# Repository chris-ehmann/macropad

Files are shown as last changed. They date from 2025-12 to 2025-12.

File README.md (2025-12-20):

# Macropad

I've been interested in mechanical keyboards for a while now, and recently I wanted to get a bit of experience writing firmware, so I decided to combine these two interests and create a mechanical keyboard from scratch (well, as close to "from scratch" as reasonably possible).

## Designing the PCB

The hardware design for a keyboard is fairly straightforward. A lot of credit here goes to ai03's guide located [here](https://wiki.ai03.com/books/pcb-design/), which gives pretty good direction on what a properly designed circuit should look like. Of course, I wanted to actually learn what was going on in the circuit that I was replicating, so I made sure to supplement this with reading through datasheets and general studying. I think I can confidently state what a pull-up resistor now does, at the very least.

Even though this is a 6-key keypad (which means each switch could be directly connected to it's own pin), I thought a keyboard matrix circuit would be more fun to implement. The premise here is pretty straightforward: since there aren't enough pins on microcontrollers to directly connect each switch to a key, you have to get a bit creative and arrange switches in a grid-like formation. Then, each switch will be connected to a specific grid pin and to a specific row pin. Now, say you have current flowing through a specific column, if any of the keys connected in that column are pressed, you'll be able to figure that out by simplying checking the corresponding row pins for any input. There's a few things to be considerate of however -- primarily [ghosting](https://www.dribin.org/dave/keyboard/one_html/).

## Soldering

I've never soldered before, so I thought this would be a great opportunity to learn. There's a few components that I thought would be near impossible for me to solder as a beginner (e.g., the USB Micro-B connector, the ATMEGA32U4 microcontroller, and whatever other SMD  components), so I opted for these to be assembled by the PCB manufacturer (in my case, JLCPCB). The switches however, being through-hole, felt a little bit more in my ballpark. 

For soldering equipment, I didn't have anything on hand so I ended up grabbing myself a [PINECIL](https://pine64.com/product/pinecil-smart-mini-portable-soldering-iron/). It seems to be pretty highly recommended and I can understand why; it felt very easy to use. Maybe in the future if I do more soldering I might pick up something more heavy-duty, like a hot air rework station.

## Firmware

The firmware I've written for this uses [LUFA](https://github.com/abcminiuser/lufa) to communicate via USB. I'm new to this framework, so I've built upon the Keyboard demo that's generously provided with LUFA. The relevant keypad code (e.g. what actually sets up our pins, scans through the matrix, handles debouncing, etc.) can be found in `macropad_firmware/macropad_firmware/Keyboard.c`. I do eventually want to move this out of a demo and into something built up from scratch (albeit while still using LUFA), but for now this has worked very well for a first revision.

The firmware is pretty basic: for scanning the matrix, we set each row to output LOW, and then we scan each column (configured to be input with pull-up resistor active) to detect which keys are pressed. We then store the number of scan-cycles a key has been pressed for, and once it hits some debouncing threshold (I've chosen 10, which corresponds to about a 5ms debounce period. The datasheet for the Cherry-MX Brown switches that I'm using state that the bounce time is <2 msec, so it's slightly overkill) we can then send it over in the next USB report.

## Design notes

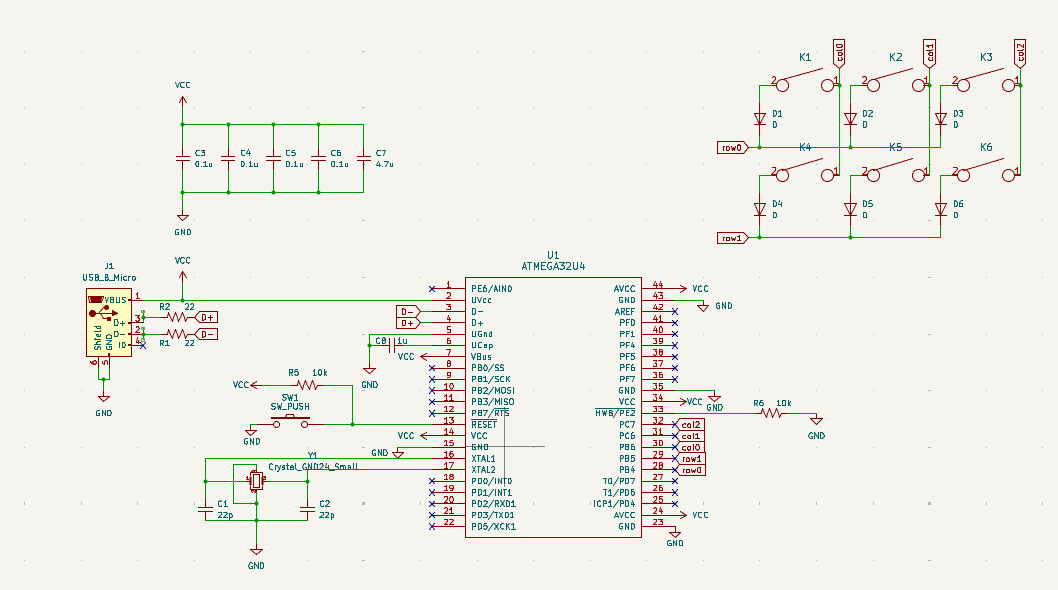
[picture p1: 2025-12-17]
macropad/macropad_schematic.png

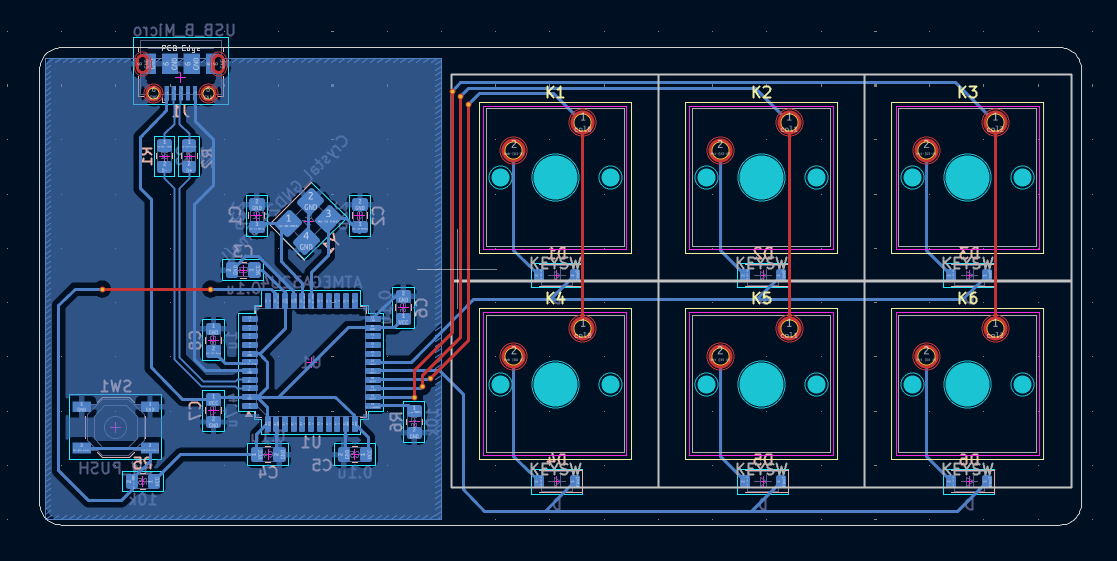
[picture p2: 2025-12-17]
macropad/macropad_pcb.png

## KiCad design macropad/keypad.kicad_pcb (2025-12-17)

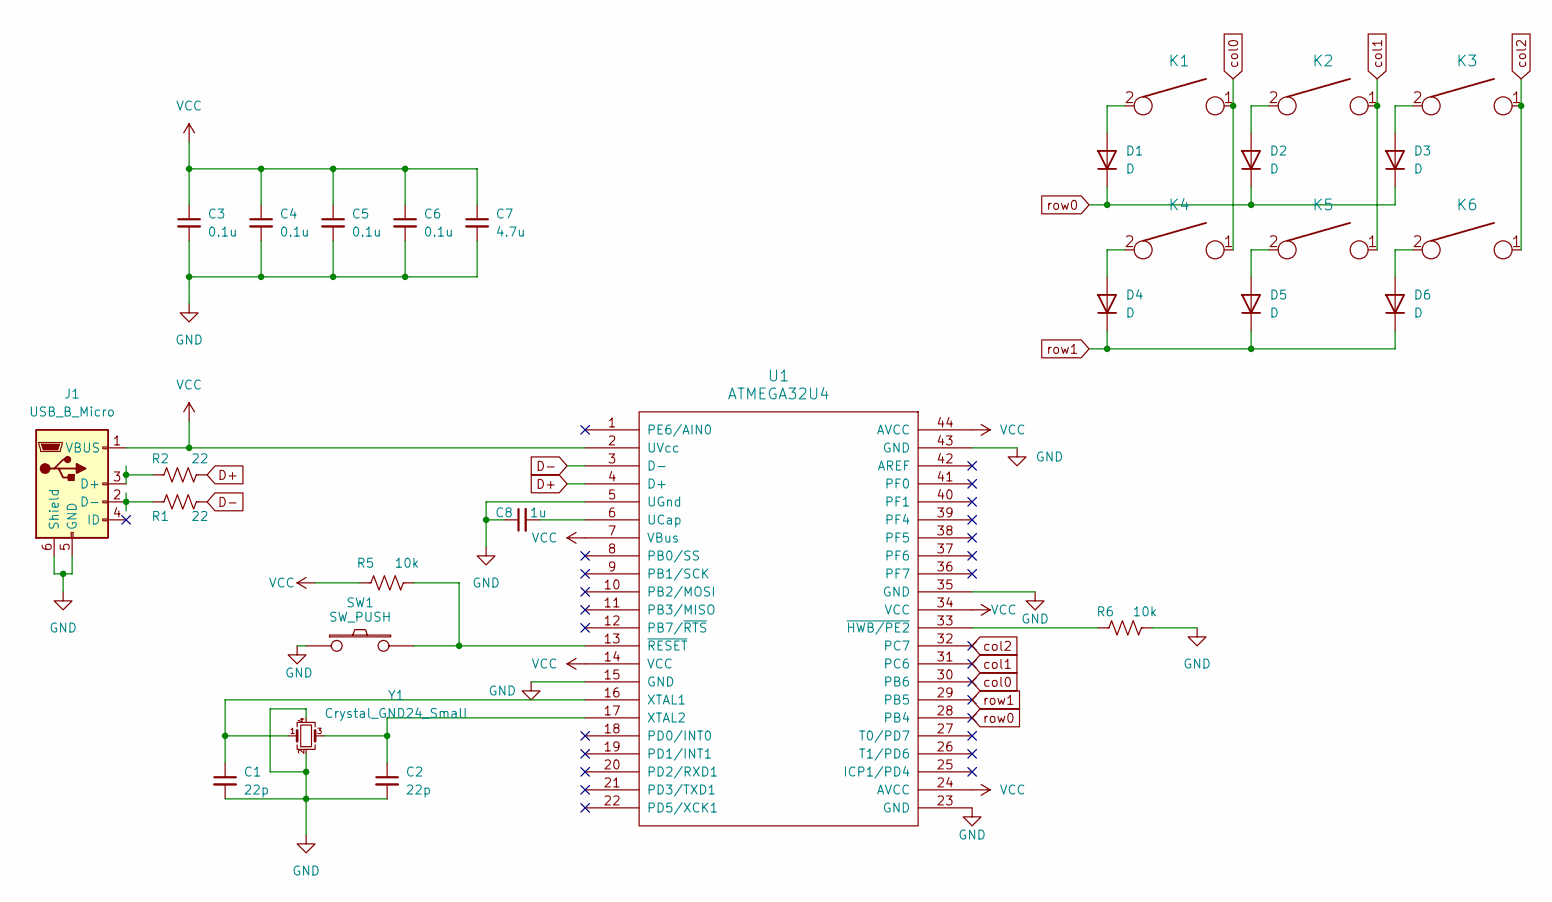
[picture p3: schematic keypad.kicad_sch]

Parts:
C1, C2: 22p; C_0805_2012Metric_Pad1.18x1.45mm_HandSolder
C3, C4, C5, C6: 0.1u; C_0805_2012Metric_Pad1.18x1.45mm_HandSolder
C7: 4.7u; C_0805_2012Metric_Pad1.18x1.45mm_HandSolder
C8: 1u; C_0805_2012Metric_Pad1.18x1.45mm_HandSolder
D1, D2, D3, D4, D5, D6: D; D_SOD-123
J1: USB_B_Micro; USB_Micro-B_Molex-105017-0001
K1, K2, K3, K4, K5, K6: KEYSW; SW_Cherry_MX_1.00u_PCB
R1, R2: 22; R_0805_2012Metric_Pad1.20x1.40mm_HandSolder
R5, R6: 10k; R_0805_2012Metric_Pad1.20x1.40mm_HandSolder
SW1: SW_PUSH; SW_SPST_TL3342
U1: ATMEGA32U4; TQFP-44_10x10mm_P0.8mm
Y1: Crystal_GND24_Small; Crystal_SMD_3225-4Pin_3.2x2.5mm_HandSoldering

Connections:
D+: R2.2, U1.4 (D+)
D-: R1.2, U1.3 (D-)
GND: C1.2, C2.2, C3.2, C4.2, C5.2, C6.2, C7.2, C8.1, J1.5 (GND), J1.6 (Shield), R6.2, SW1.1, U1.5 (UGnd), U1.15 (GND), U1.23 (GND), U1.35 (GND), U1.43 (GND), Y1.2, Y1.4
unnamed: D1.2 (A), K1.2
unnamed: D2.2 (A), K2.2
unnamed: D3.2 (A), K3.2
unnamed: D4.2 (A), K4.2
unnamed: D5.2 (A), K5.2
unnamed: D6.2 (A), K6.2
unnamed: J1.3 (D+), R2.1
unnamed: J1.2 (D-), R1.1
unnamed: C8.2, U1.6 (UCap)
unnamed: C1.1, U1.16 (XTAL1), Y1.1
unnamed: C2.1, U1.17 (XTAL2), Y1.3
unnamed: R6.1, U1.33 (~HWB/PE2)
unnamed: R5.2, SW1.2, U1.13 (~RESET)
VCC: C3.1, C4.1, C5.1, C6.1, C7.1, J1.1 (VBUS), R5.1, U1.2 (UVcc), U1.7 (VBus), U1.14 (VCC), U1.24 (AVCC), U1.34 (VCC), U1.44 (AVCC)
col0: K1.1, K4.1, U1.30 (PB6)
col1: K2.1, K5.1, U1.31 (PC6)
col2: K3.1, K6.1, U1.32 (PC7)
row0: D1.1 (K), D2.1 (K), D3.1 (K), U1.28 (PB4)
row1: D4.1 (K), D5.1 (K), D6.1 (K), U1.29 (PB5)

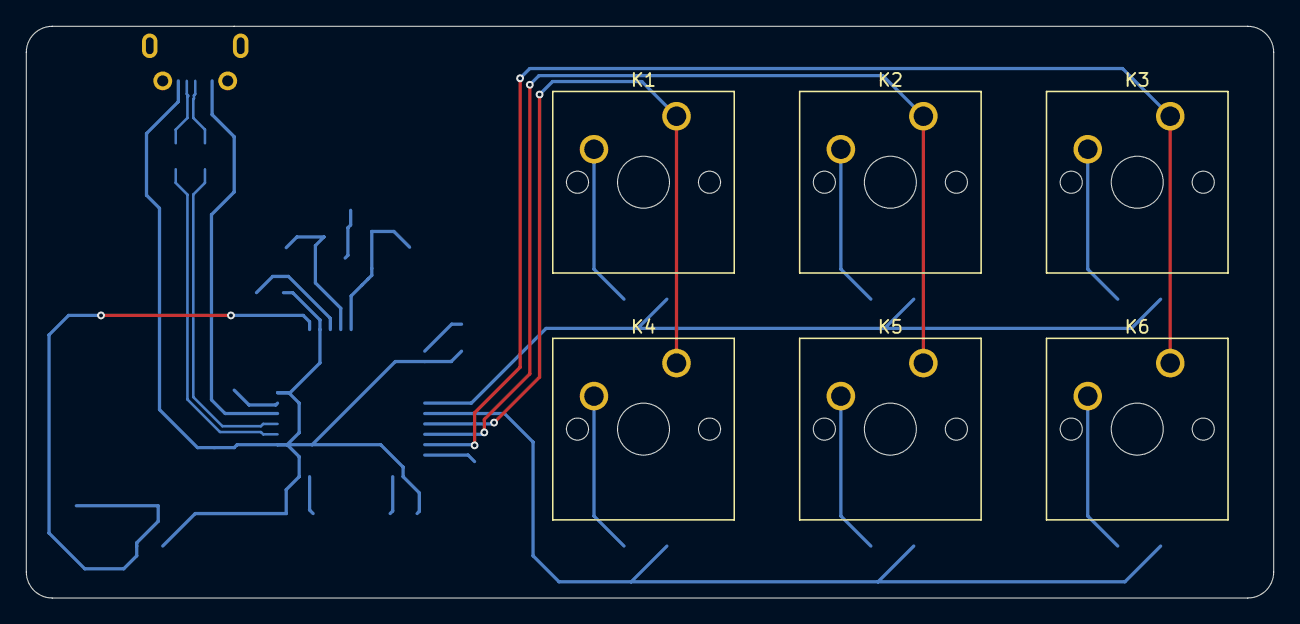
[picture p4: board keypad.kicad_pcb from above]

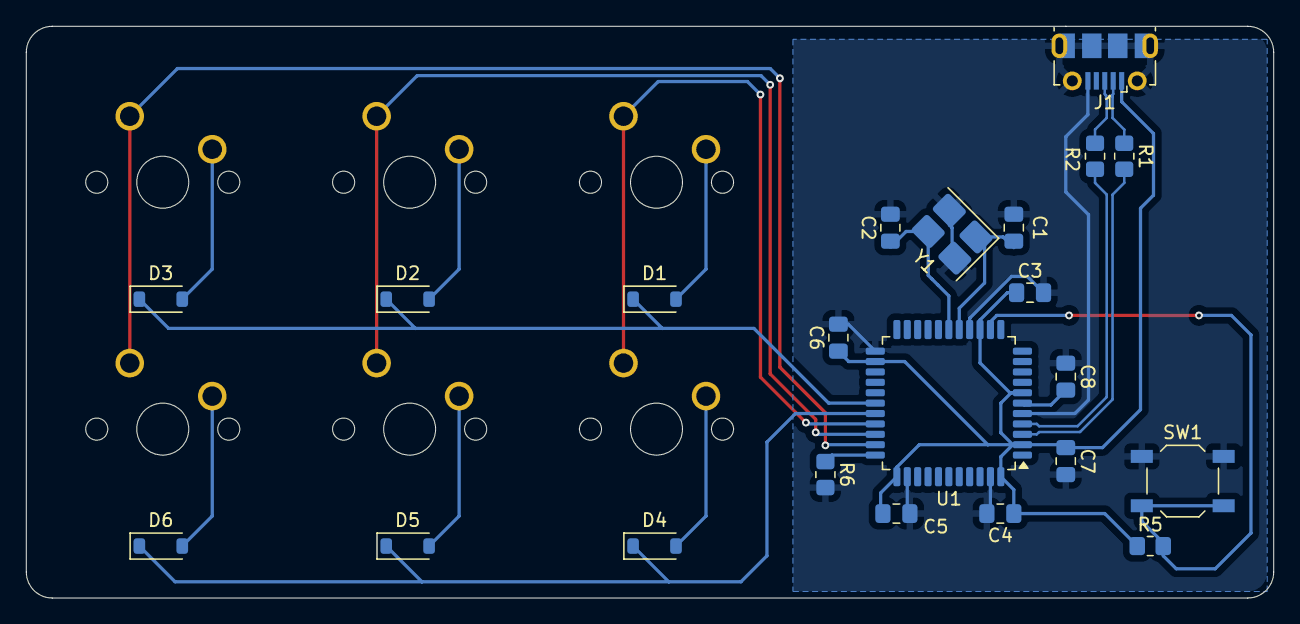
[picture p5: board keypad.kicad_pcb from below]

Board: 2 copper layers, 96.0 x 44.0 mm, 28 parts (22 on the bottom side), 22 nets.

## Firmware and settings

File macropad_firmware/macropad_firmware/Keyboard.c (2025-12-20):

/*
             LUFA Library
     Copyright (C) Dean Camera, 2017.

  dean [at] fourwalledcubicle [dot] com
           www.lufa-lib.org
*/

/*
  Copyright 2017  Dean Camera (dean [at] fourwalledcubicle [dot] com)
  Copyright 2010  Denver Gingerich (denver [at] ossguy [dot] com)

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
  The author disclaims all warranties with regard to this
  software, including all implied warranties of merchantability
  and fitness.  In no event shall the author be liable for any
  special, indirect or consequential damages or any damages
  whatsoever resulting from loss of use, data or profits, whether
  in an action of contract, negligence or other tortious action,
  arising out of or in connection with the use or performance of
  this software.
*/

#include "Keyboard.h"
#include <stdint.h>
#include <util/delay.h>

/** Indicates what report mode the host has requested, true for normal HID reporting mode, \c false for special boot
 *  protocol reporting mode.
 */
static bool UsingReportProtocol = true;

/** Current Idle period. This is set by the host via a Set Idle HID class request to silence the device's reports
 *  for either the entire idle duration, or until the report status changes (e.g. the user presses a key).
 */
static uint16_t IdleCount = 500;

/** Current Idle period remaining. When the IdleCount value is set, this tracks the remaining number of idle
 *  milliseconds. This is separate to the IdleCount timer and is incremented and compared as the host may request
 *  the current idle period via a Get Idle HID class request, thus its value must be preserved.
 */
static uint16_t IdleMSRemaining = 0;

#define DEBOUNCE_THRESHOLD  10
#define LAYER_SWITCH        0x00
#define NUM_COLS            3
#define NUM_ROWS            2
#define PIN_DEF(port, pin)  { &PIN##port, &DDR##port, &PORT##port, pin }
#define layer_count(a)      (sizeof(a) / sizeof(a[0]))
	
typedef struct
{
	volatile uint8_t *pin;
	volatile uint8_t *ddr;
	volatile uint8_t *port;
	uint8_t pin_n;
} gpio_pin_t;

const gpio_pin_t COLS[NUM_COLS]							   = { PIN_DEF(B, 6), PIN_DEF(C, 6), PIN_DEF(C, 7) };
const gpio_pin_t ROWS[NUM_ROWS]						       = { PIN_DEF(B, 4), PIN_DEF(B, 5) };
uint8_t debounce_keys[NUM_ROWS][NUM_COLS]				   = {{0, 0, 0}, {0, 0, 0}}; // Matrix to store the amount of cycles a key has been held down for. Caps out at DEBOUNCE_THRESHOLD to avoid integer overflow
	
// Matrix that stores each layer of our keypad. Key in row 0 column 0 is marked as LAYER_SWITCH as it corresponds
// to a special key on the keyboard that swaps between layers (and doesn't actually send any data)
const unsigned char keycodes[][NUM_ROWS][NUM_COLS] PROGMEM = 
  															 { { {LAYER_SWITCH, HID_KEYBOARD_SC_4_AND_DOLLAR, HID_KEYBOARD_SC_5_AND_PERCENTAGE},
															     {HID_KEYBOARD_SC_1_AND_EXCLAMATION, HID_KEYBOARD_SC_2_AND_AT, HID_KEYBOARD_SC_3_AND_HASHMARK}, },
														
															   { {LAYER_SWITCH, HID_KEYBOARD_SC_9_AND_OPENING_PARENTHESIS, HID_KEYBOARD_SC_0_AND_CLOSING_PARENTHESIS},
															     {HID_KEYBOARD_SC_6_AND_CARET, HID_KEYBOARD_SC_7_AND_AMPERSAND, HID_KEYBOARD_SC_8_AND_ASTERISK} } };
												   
/*  Keyboard layout, as a diagram (! designates SWAP layer key)
	NOTE: Only top layer keys are shown
   +-----------------------------+
   |         |         |         |
   |    !    |    4    |    5    |
   |         |         |         |
   +-----------------------------+
   |         |         |         |
   |    1    |    2    |    3    |
   |         |         |         |
   +-----------------------------+
*/

// Set up appropriate GPIO pins for keypad matrix
static void io_config()
{
	// Initially set up our row pins (which will be used as output pins) as input (Hi-Z)
	for(int i = 0; i < NUM_ROWS; i++)
	{
		*ROWS[i].ddr &= ~(1 << ROWS[i].pin_n);
	}
	
	// Set up our column pins to be input and activate the internal pull-up resistor
	for(int i = 0; i < NUM_COLS; i++)
	{
		*COLS[i].ddr &= ~(1 << COLS[i].pin_n);
		*COLS[i].port |= (1 << COLS[i].pin_n);
	}
}

static bool is_key_pressed(uint8_t row, uint8_t col)
{
	return debounce_keys[row][col] == DEBOUNCE_THRESHOLD;
}

// Performs a scan over the entire keyboard matrix and updates key states accordingly
static void scan_matrix()
{
	for(uint8_t row = 0; row < NUM_ROWS; row++)
	{
		// Set current row to output; drive it low
		*ROWS[row].ddr |= (1 << ROWS[row].pin_n);
		*ROWS[row].port &= ~(1 << ROWS[row].pin_n);
			
		// Slight delay to allow row to settle
		_delay_us(20);
			
		// Iterate over each column to detect which keys are pressed in this row
		for(uint8_t col = 0; col < NUM_COLS; col++)
		{
			uint8_t pressed = 0;
			pressed = (*COLS[col].pin & (1 << COLS[col].pin_n)) == 0; // Check if pin corresponding to column is low (meaning the key is pressed) or high (key is not pressed)
			if(pressed)
			{
				if(debounce_keys[row][col] < DEBOUNCE_THRESHOLD)
				{
					debounce_keys[row][col]++;
				}
				continue;
			}

			if(debounce_keys[row][col] > 0)
			{
				debounce_keys[row][col]--;
			}
		}
		
		// Switch row back to being input
		*ROWS[row].ddr &= ~(1 << ROWS[row].pin_n);
	}	
}

int main(void)
{
	SetupHardware();
	io_config();
	GlobalInterruptEnable();

	while(1)
	{
		scan_matrix();
		
		// Send data (either pressed keys, or nothing) through USB connection
		HID_Task();
		USB_USBTask();
		
		// Half a millisecond delay between full scans corresponds to about 5ms to fully debounce a key (given DEBOUNCE_THRESHOLD = 10)
		_delay_us(500);
	}
}

/** Configures the board hardware and chip peripherals for the demo's functionality. */
void SetupHardware(void)
{
	/* Disable watchdog if enabled by bootloader/fuses */
	MCUSR &= ~(1 << WDRF);
	wdt_disable();

	/* Disable clock division */
	clock_prescale_set(clock_div_1);
	USB_Init();
}

/** Event handler for the USB_ConfigurationChanged event. This is fired when the host sets the current configuration
 *  of the USB device after enumeration, and configures the keyboard device endpoints.
 */
void EVENT_USB_Device_ConfigurationChanged(void)
{
	bool ConfigSuccess = true;

	/* Setup HID Report Endpoints */
	ConfigSuccess &= Endpoint_ConfigureEndpoint(KEYBOARD_IN_EPADDR, EP_TYPE_INTERRUPT, KEYBOARD_EPSIZE, 1);
	ConfigSuccess &= Endpoint_ConfigureEndpoint(KEYBOARD_OUT_EPADDR, EP_TYPE_INTERRUPT, KEYBOARD_EPSIZE, 1);

	/* Turn on Start-of-Frame events for tracking HID report period expiry */
	USB_Device_EnableSOFEvents();
}

/** Event handler for the USB_ControlRequest event. This is used to catch and process control requests sent to
 *  the device from the USB host before passing along unhandled control requests to the library for processing
 *  internally.
 */
void EVENT_USB_Device_ControlRequest(void)
{
	/* Handle HID Class specific requests */
	switch (USB_ControlRequest.bRequest)
	{
		case HID_REQ_GetReport:
			if (USB_ControlRequest.bmRequestType == (REQDIR_DEVICETOHOST | REQTYPE_CLASS | REQREC_INTERFACE))
			{
				USB_KeyboardReport_Data_t KeyboardReportData;

				/* Create the next keyboard report for transmission to the host */
				CreateKeyboardReport(&KeyboardReportData);

				Endpoint_ClearSETUP();

				/* Write the report data to the control endpoint */
				Endpoint_Write_Control_Stream_LE(&KeyboardReportData, sizeof(KeyboardReportData));
				Endpoint_ClearOUT();
			}

			break;
		case HID_REQ_SetReport:
			if (USB_ControlRequest.bmRequestType == (REQDIR_HOSTTODEVICE | REQTYPE_CLASS | REQREC_INTERFACE))
			{
				Endpoint_ClearSETUP();

				/* Wait until the LED report has been sent by the host */
				while (!(Endpoint_IsOUTReceived()))
				{
					if (USB_DeviceState == DEVICE_STATE_Unattached)
					  return;
				}

				Endpoint_ClearOUT();
				Endpoint_ClearStatusStage();
			}

			break;
		case HID_REQ_GetProtocol:
			if (USB_ControlRequest.bmRequestType == (REQDIR_DEVICETOHOST | REQTYPE_CLASS | REQREC_INTERFACE))
			{
				Endpoint_ClearSETUP();

				/* Write the current protocol flag to the host */
				Endpoint_Write_8(UsingReportProtocol);

				Endpoint_ClearIN();
				Endpoint_ClearStatusStage();
			}

			break;
		case HID_REQ_SetProtocol:
			if (USB_ControlRequest.bmRequestType == (REQDIR_HOSTTODEVICE | REQTYPE_CLASS | REQREC_INTERFACE))
			{
				Endpoint_ClearSETUP();
				Endpoint_ClearStatusStage();

				/* Set or clear the flag depending on what the host indicates that the current Protocol should be */
				UsingReportProtocol = (USB_ControlRequest.wValue != 0);
			}

			break;
		case HID_REQ_SetIdle:
			if (USB_ControlRequest.bmRequestType == (REQDIR_HOSTTODEVICE | REQTYPE_CLASS | REQREC_INTERFACE))
			{
				Endpoint_ClearSETUP();
				Endpoint_ClearStatusStage();

				/* Get idle period in MSB, IdleCount must be multiplied by 4 to get number of milliseconds */
				IdleCount = ((USB_ControlRequest.wValue & 0xFF00) >> 6);
			}

			break;
		case HID_REQ_GetIdle:
			if (USB_ControlRequest.bmRequestType == (REQDIR_DEVICETOHOST | REQTYPE_CLASS | REQREC_INTERFACE))
			{
				Endpoint_ClearSETUP();

				/* Write the current idle duration to the host, must be divided by 4 before sent to host */
				Endpoint_Write_8(IdleCount >> 2);

				Endpoint_ClearIN();
				Endpoint_ClearStatusStage();
			}

			break;
	}
}

/** Event handler for the USB device Start Of Frame event. */
void EVENT_USB_Device_StartOfFrame(void)
{
	/* One millisecond has elapsed, decrement the idle time remaining counter if it has not already elapsed */
	if (IdleMSRemaining)
	  IdleMSRemaining--;
}

/** Fills the given HID report data structure with the next HID report to send to the host.
 *
 *  \param[out] ReportData  Pointer to a HID report data structure to be filled
 */
void CreateKeyboardReport(USB_KeyboardReport_Data_t* const ReportData)
{
	uint8_t UsedKeyCodes = 0;
	uint8_t active_layer = is_key_pressed(0, 0) ? 1 : 0;

	/* Clear the report contents */
	memset(ReportData, 0, sizeof(USB_KeyboardReport_Data_t));
	
	for(int row = 0; row < NUM_ROWS; row++)
	{
		for(int col = 0; col < NUM_COLS; col++)
		{
			// The current keypad this firmware is set up for is only 6 keys (5 excluding the layer switch key), 
			// but just to be safe we limit the amount of keys sent to the maximum that can be sent in one report (which is 6, see https://www.usb.org/document-library/device-class-definition-hid-111)
			if(is_key_pressed(row, col) && UsedKeyCodes < 6)
			{
				if(row == 0 && col == 0)
				{
					continue;
				}
				
				ReportData->KeyCode[UsedKeyCodes++] = pgm_read_byte(&keycodes[active_layer][row][col]);
			}
		}
	}
}

/** Sends the next HID report to the host, via the keyboard data endpoint. */
void SendNextReport(void)
{
	static USB_KeyboardReport_Data_t PrevKeyboardReportData;
	USB_KeyboardReport_Data_t        KeyboardReportData;
	bool                             SendReport = false;

	/* Create the next keyboard report for transmission to the host */
	CreateKeyboardReport(&KeyboardReportData);

	/* Check if the idle period is set and has elapsed */
	if (IdleCount && (!(IdleMSRemaining)))
	{
		/* Reset the idle time remaining counter */
		IdleMSRemaining = IdleCount;

		/* Idle period is set and has elapsed, must send a report to the host */
		SendReport = true;
	}
	else
	{
		/* Check to see if the report data has changed - if so a report MUST be sent */
		SendReport = (memcmp(&PrevKeyboardReportData, &KeyboardReportData, sizeof(USB_KeyboardReport_Data_t)) != 0);
	}

	/* Select the Keyboard Report Endpoint */
	Endpoint_SelectEndpoint(KEYBOARD_IN_EPADDR);

	/* Check if Keyboard Endpoint Ready for Read/Write and if we should send a new report */
	if (Endpoint_IsReadWriteAllowed() && SendReport)
	{
		/* Save the current report data for later comparison to check for changes */
		PrevKeyboardReportData = KeyboardReportData;

		/* Write Keyboard Report Data */
		Endpoint_Write_Stream_LE(&KeyboardReportData, sizeof(KeyboardReportData), NULL);

		/* Finalize the stream transfer to send the last packet */
		Endpoint_ClearIN();
	}
}

/** Function to manage HID report generation and transmission to the host, when in report mode. */
void HID_Task(void)
{
	/* Device must be connected and configured for the task to run */
	if (USB_DeviceState != DEVICE_STATE_Configured)
	  return;

	/* Send the next keypress report to the host */
	SendNextReport();
}

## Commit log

2025-12-17 Add KiCad files
    Includes schematic and PCB
    [keypad.kicad_pcb, keypad.kicad_sch]
2025-12-17 Add PCB and schematic image
